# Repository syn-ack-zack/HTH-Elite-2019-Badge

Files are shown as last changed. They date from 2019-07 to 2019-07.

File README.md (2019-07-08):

# Hackers Teaching Hackers 2019 Badge
This repository contains the hardware and software source code to fabrciate the HTH 2019 Badge. Details on the use and flashing of the badge can be found below. 

HTH Badge

## Badge Hardware Specs
* ESP32
* Atmel 32u4
* 96×64 Graphic Full Color OLED Display
* 19x Mini NeoPixel RGB LEDs
* 4 tactile buttons
* 8 Mb Storage
* 1 2x3 "Shitty Add On" Connector
* Powered via 2 AA batteries or USB

## Badge Functions
* LoRa Arsenal
	* LoRa 915Mhz Tactile Button Chat
	* LoRa 915Mhz Web App Chatroom
* WiFi Tools
	* 802.11 channel activity monitor
	* Access point scanner / Open AP detector
	* Packet Monitor and Deauth sniffer
	* Can act as a client or access point (modify config.json via SPIFFS to update AP connection details)
	* Webserver (edit filesystem files, trigger payloads remotely)
	* NTP client
* HID Toolkit (Not Working)
	* An issue with the serial communication currently prevents the ESP32 from controlling the Atmega. 
	* Any HID functionality must be standalone and flashed to the Atmega.
	* This repo will be updated as any changes occur.
	
* LED patterns and OLED graphics
* Misc. extras

## Usage Instructions
### Power Switch
In order to turn on the device, it must be powered via 2 AA batteries or USB. The main power switch is located in the center.

### Buttons / UI

Up and Down is on the left side of the OLED, and Left and Right is on the right side of the OLED.

In order to go into a menu or run a program, click the right button. To exit most applications, click the left button. Some programs like the snake game require all 4 buttons so there is no way to clean exit, a power cycle is needed. 

### HTH NET (LoRa 915Mhz)
This badge contains an SX1278 LoRa transceiver which allows for long range low bandwidth communication using the LoRa protocol over 915Mhz. Each badge is capable of receiving and sending messages using this frequency by utilizing the HTH NET feature of the badge. 

Once you start the chat it will display any received message on the screen. Follow the on screen prompts to type out and send messages. The '~' is used as a delimiter to signify the end of a typed message. 

Alternatively you can utililze the Webserver by first starting up the Access Point at `WiFi Server Tools -> AP Start`. Connect to this network and then start up the Webserver at `WiFi Server Tools -> Webserver Start`. Navigate to the indicated IP, http://10.0.1.5/ to access the web app. HTH Net can be utilized here to have a more convenient interface to send and recieve LoRa messages. 



### Webserver
Navigate to WiFi Server Tools -> Webserver Start. You can access the webserver if running an AP or if connected. The pages are protected through basic authentication, username and password generated dynamically and is provided on the screen.

A SPIFFS Editor can be used to edit the flash filesystem on the badge. This is useful to modify config files which are used in several instances. For instance, to have your badge connect to another wireless network, you configure the ESSID and Password in `config.json`. 

### Bling
There are 40+ LED patterns included. You can also trigger each type of pattern individually. 

## Configuration / Customization
### Settings menu in OLED UI
There are individual settings for OLED and LED brightness. Region setting is related to WiFi channel scanning.

### JSON configuration files
There are 4 different json files in SPIFFS. There are a couple ways to edit these files and get them loaded on the badge, but the easiest is through the webserver.
1. config.json = Main device configuration. Includes parameters such as LED and OLED brightness settings, ssid/password if connecting to a wireless client network, region information, and google auth HMAC. 
2. lin.json / win.json = Configuration files for the Linux and Windows KB/M payloads. 
3. static.json = Configuration file for the stored static strings. 

## Compiling Instructions
These instructions will get you a copy of the project up and running on your local machine.
### Prerequisites
What things you need to install the software and how to install them
```
1. Arduino / compiler
2. SparkFun Pro Micro v3 com driver
https://learn.sparkfun.com/tutorials/pro-micro--fio-v3-hookup-guide/installing-windows
https://learn.sparkfun.com/tutorials/pro-micro--fio-v3-hookup-guide/installing-mac--linux
3. Libraries
  https://raw.githubusercontent.com/sparkfun/Arduino_Boards/master/IDE_Board_Manager/package_sparkfun_index.json
  https://github.com/adafruit/Adafruit_NeoPixel
  https://github.com/adafruit/Adafruit-GFX-Library
  https://github.com/adafruit/Adafruit_CircuitPlayground
  https://github.com/kitesurfer1404/WS2812FX
  https://github.com/me-no-dev/ESPAsyncWebServer
  https://github.com/me-no-dev/AsyncTCP
  https://github.com/bblanchon/ArduinoJson
  https://github.com/me-no-dev/arduino-esp32fs-plugin
  https://github.com/sandeepmistry/arduino-LoRa
  Manually copy the SSD_13XX and qMenuSystem folders to Arduino libraries folder. We included a snapshot of the other libraries used in case newer versions break our code.
4. 3.3v FTDI serial cable
5. Hackers Teaching Hackers 2019 Badge
```
### Compiling / Flashing Atmel Code
* Set the board to SparkFun Pro Micro
* Set the processor as ATmega32u4 3.3v and NOT the 5v one

### Compiling / Flashing ESP Code
* Set the board to SparkFun ESP32 Thing

#### Programming through FTDI port 
To interface with the ESP32 over FTDI serial, you will need a FTDI USB adapter. These can be found online or at some retailers like MicroCenter. [FTDI Adapter on Amazon](https://www.amazon.com/HiLetgo-FT232RL-Converter-Adapter-Breakout/dp/B00IJXZQ7C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)

1. Flash the atmel with the 'atmel-esp32ftdi-pin7' code first via the USB connection. this will toggle pin 7 and the rx/tx switch to change the serial port communiction to the FTDI port. 
2. Connect FTDI cable to the board while holding the left button down (which is on the right side, top button)
3. Upload code.
4. You can optionally flash the 'atmel-km-relay' code back to the atmel. Most serial functionality isn't working correctly at this time, however the mouse jiggler feature is configured to work when plugged in. Note that you may need to reset the the atmel by shorting GND to [Pin 13](https://www.arduino.cc/en/Hacking/PinMapping32u4) before succesfully reflashing. 

#### Programming through USB port / Atmel
Pass through programming doesn't work at the time of writing. Communication is passed through, but something is holding up the ESP32 from fully going into the programming mode

### Uploading SPIFFS files
The keyboard/mouse payloads, configuration files, webserver files are all files that are loaded into a special section in storage marked as SPIFFS. While still having pin 7 set to allow for the FTDI connection, use the 'ESP32 Sketch Data Upload' function in the tools menu. This will compress and compile all the files in the 'data' folder, and upload it. 

## Authors / Contributors
* **@syn-ack-zack**

## Acknowledgments
* Thanks to all contributes and maintainers of any codebase which was used or referenced. 
* Special thanks to Hacker Warehouse and Garret Gee for the work on their [DC26 badge](https://github.com/hackerwarehouse/HW-DC26-Badge). Much of the materials around the core components (esp32 / atmega34u ) was referenced from Hacker Warehouse's open sourced badge.

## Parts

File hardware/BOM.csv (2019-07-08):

 | Note | part number | Quantity | Description | Alternative Part Number | Reference Designator
 |  | CL10C220JB8NNNC | 2 | 22PF 50V NP0 0603 Capacitor | C1608C0G1H220G080AA | C2, C3
 | 5-7work days | F931C106MAAAJ6 | 2 | 10uf Tantalum Capacitor 1206 16V 20% | F931C106MAA | C4, C8
 |  | C1608X6S1C475K080AC | 1 | 4.7UF 16V X5R 0603 |  | C46
 |  | CL10A106MA8NRNC | 4 | 10uF 25V 20% 0603 Capacitor |  | C6, C9, C10, C24
 | TME MOQ:100pcs 5-7work days | CL10B103KC8NNNC | 1 | .01uf/10nf 100V 0603 10% Capacitor |  | C20
 |  | CC0603MRY5V6BB105 | 5 | 1uf 16V 10% 0603 Capacitor | CL10A105KO8NNNC | C1, C29, C44, C45, C47
 | 5-7work days | 06033C104KAZ2A | 27 | 0.1uf 25V 10% 0603 Capacitor | CL10B104KA8NNNC | C5, C7, C21, C23, C25, C26, C27, C28, C30, C31, C32, C33, C34, C35, C36, C37, C38, C39, C40, C41, C42, C43, C48, C49, C50, C51, C55
 |  | VJ0603Y332KXJCW1BC | 1 | 3.3nf 16V 10% 0603 Capacitor |  | C19
 | 5-7work days | GRM1885C2A101JA01D | 1 | 100pf/0.1nf 100V 0603 Capacitor |  | C22
 |  | C1608C0G1H100C080AA | 2 | 10pF 脗卤0.25pF 50V Ceramic Capacitor C0G, NP0 0603 |  | C13, C16
 |  | CL10C5R6DB8NNNC | 1 | 5.6pF Ceramic Capacitor +-0.5pF 50V 0603 |  | C11
 |  | CC0603JRNPO9BN150 | 2 | CAP CER 15PF 50V C0G/NPO 0603 |  | C14, C15
 |  | CL10C2R4CB8NNNC | 1 | CAP CER 2.4PF 50V C0G/NP0 0603 |  | C12
 |  | CL10B271KB8NNNC | 2 | CAP CER 270PF 50V X7R 0603 |  | C17, C18
 |  | SS1P3L-M3/84A | 1 | SS1P3L Schottky Diode 30V 1A |  | D3
 |  | B140HW-7 | 2 | DIODE SCHOTTKY 40V 1A SOD123 |  | D2, D5
 | 5-7work days | 1N914BWS | 1 | Diode Standard 75V 150mA SOD-323F |  | D1
 | MOQ：1500pcs 1500pcs / bag | SK6812MINI | 19 | 3535 RGB Addressable LED |  | LED1, LED2, LED3, LED4, LED5, LED6, LED7, LED8, LED9, LED10, LED11, LED12, LED13, LED14, LED15, LED16, LED17, LED18, LED19
 | 7-10work days | AYZ0202AGRLC | 1 | DPDT Slide Switch (On/Off) SMT |  | S1
 | 7-10work days | TL3301NF100QG | 4 | Black Momentary Push Button - SMD |  | U$1, U$2, U$3, U$4
 |  | 10118194-0001LF | 1 | USB Micro-B RECPT SMD Connector |  | U$6
 | 5-7work days | BC2AAPC | 1 | Battery Holder 2-AA TH |  | U$5
 |  | ATMEGA32U4-MU | 1 | ATMEGA32U4-MU Microcontroller QFN |  | U4
 | 5-7work days | FAN5331SX | 1 | LED Driver Regulator 1A SOT23-5 |  | U1
 | 5-7work days | MIC5209-3.3YS-TR | 1 | IC REG LINEAR 3.3V 500MA SOT223 |  | U$7
 |  | 74LVC1G3157GW,125 | 2 | IC MUX/DEMUX 2X1 6TSSOP |  | U$8, U$9
 | ESP32-D0WDQ6 QFN 6*6 | ESP3212 | 1 | ESP3212 |  | U2
 | 5-7work days | TPS2113ADRBR | 1 | IC OR CTRLR SRC SELECT 8SON |  | U$10
 | 5-7work days | W25Q64JVSSIM TR | 1 | IC FLASH 64MBIT SPI 8SOIC W25Q64JVSSIM TR |  | U5
 | 5-7work days | SRU5018-100Y | 1 | 10 uH Inductor 1.8A 5028 |  | L1
 |  | HK16082N7S-T | 1 | FIXED IND 2.7NH 300MA 100 MOHM |  | L2
 |  | UG-9664HDDAG01 | 1 | 0.95 inch (96 x 64) Pixel Full Color Passive OLED LCD |  | LCD1
 |  | RC0603JR-07100KL | 3 | 100K Resistor 0603 1/10W 5% |  | R2, R6, R12
 |  | ERJ-3GEYJ102V | 1 | 1K OHM 5% 1/10W 0603 Resistor | RC0603JR-071KL | R13
 |  | RC0603JR-0710KL | 6 | 10K Resisitor 0603 1/10W 5% |  | R1, R3, R5, R7, R8, R10
 |  | RC0603FR-071ML | 1 | 1M Resistor 0603 1/10W 1% |  | R4
 |  | RC0603JR-0722RL | 2 | 22 ohm Resistor 0603 1/10W 5% |  | R14, R15
 |  | RC0603FR-0720KL | 2 | RES SMD 20K OHM 1% 1/10W 0603 |  | R9, R11
 | 5-7work days | ABM3B-8.000MHZ-B2-T | 1 | 8.0 MHz Crystal 5 mm x 3.2 mm |  | Y1
 | 5-7work days | ABS07-32.768KHZ-T | 1 | 32.768 KHz Crystal FC-135 32.7680KA-A3 | FC-135 32.7680KA-A3 | X2
 | 5-7work days | TSX-3225 26.0000MF09Z-AC0 | 1 | Crystal 26MHz 3.2 x 2.5 |  | Y2
0.5KG

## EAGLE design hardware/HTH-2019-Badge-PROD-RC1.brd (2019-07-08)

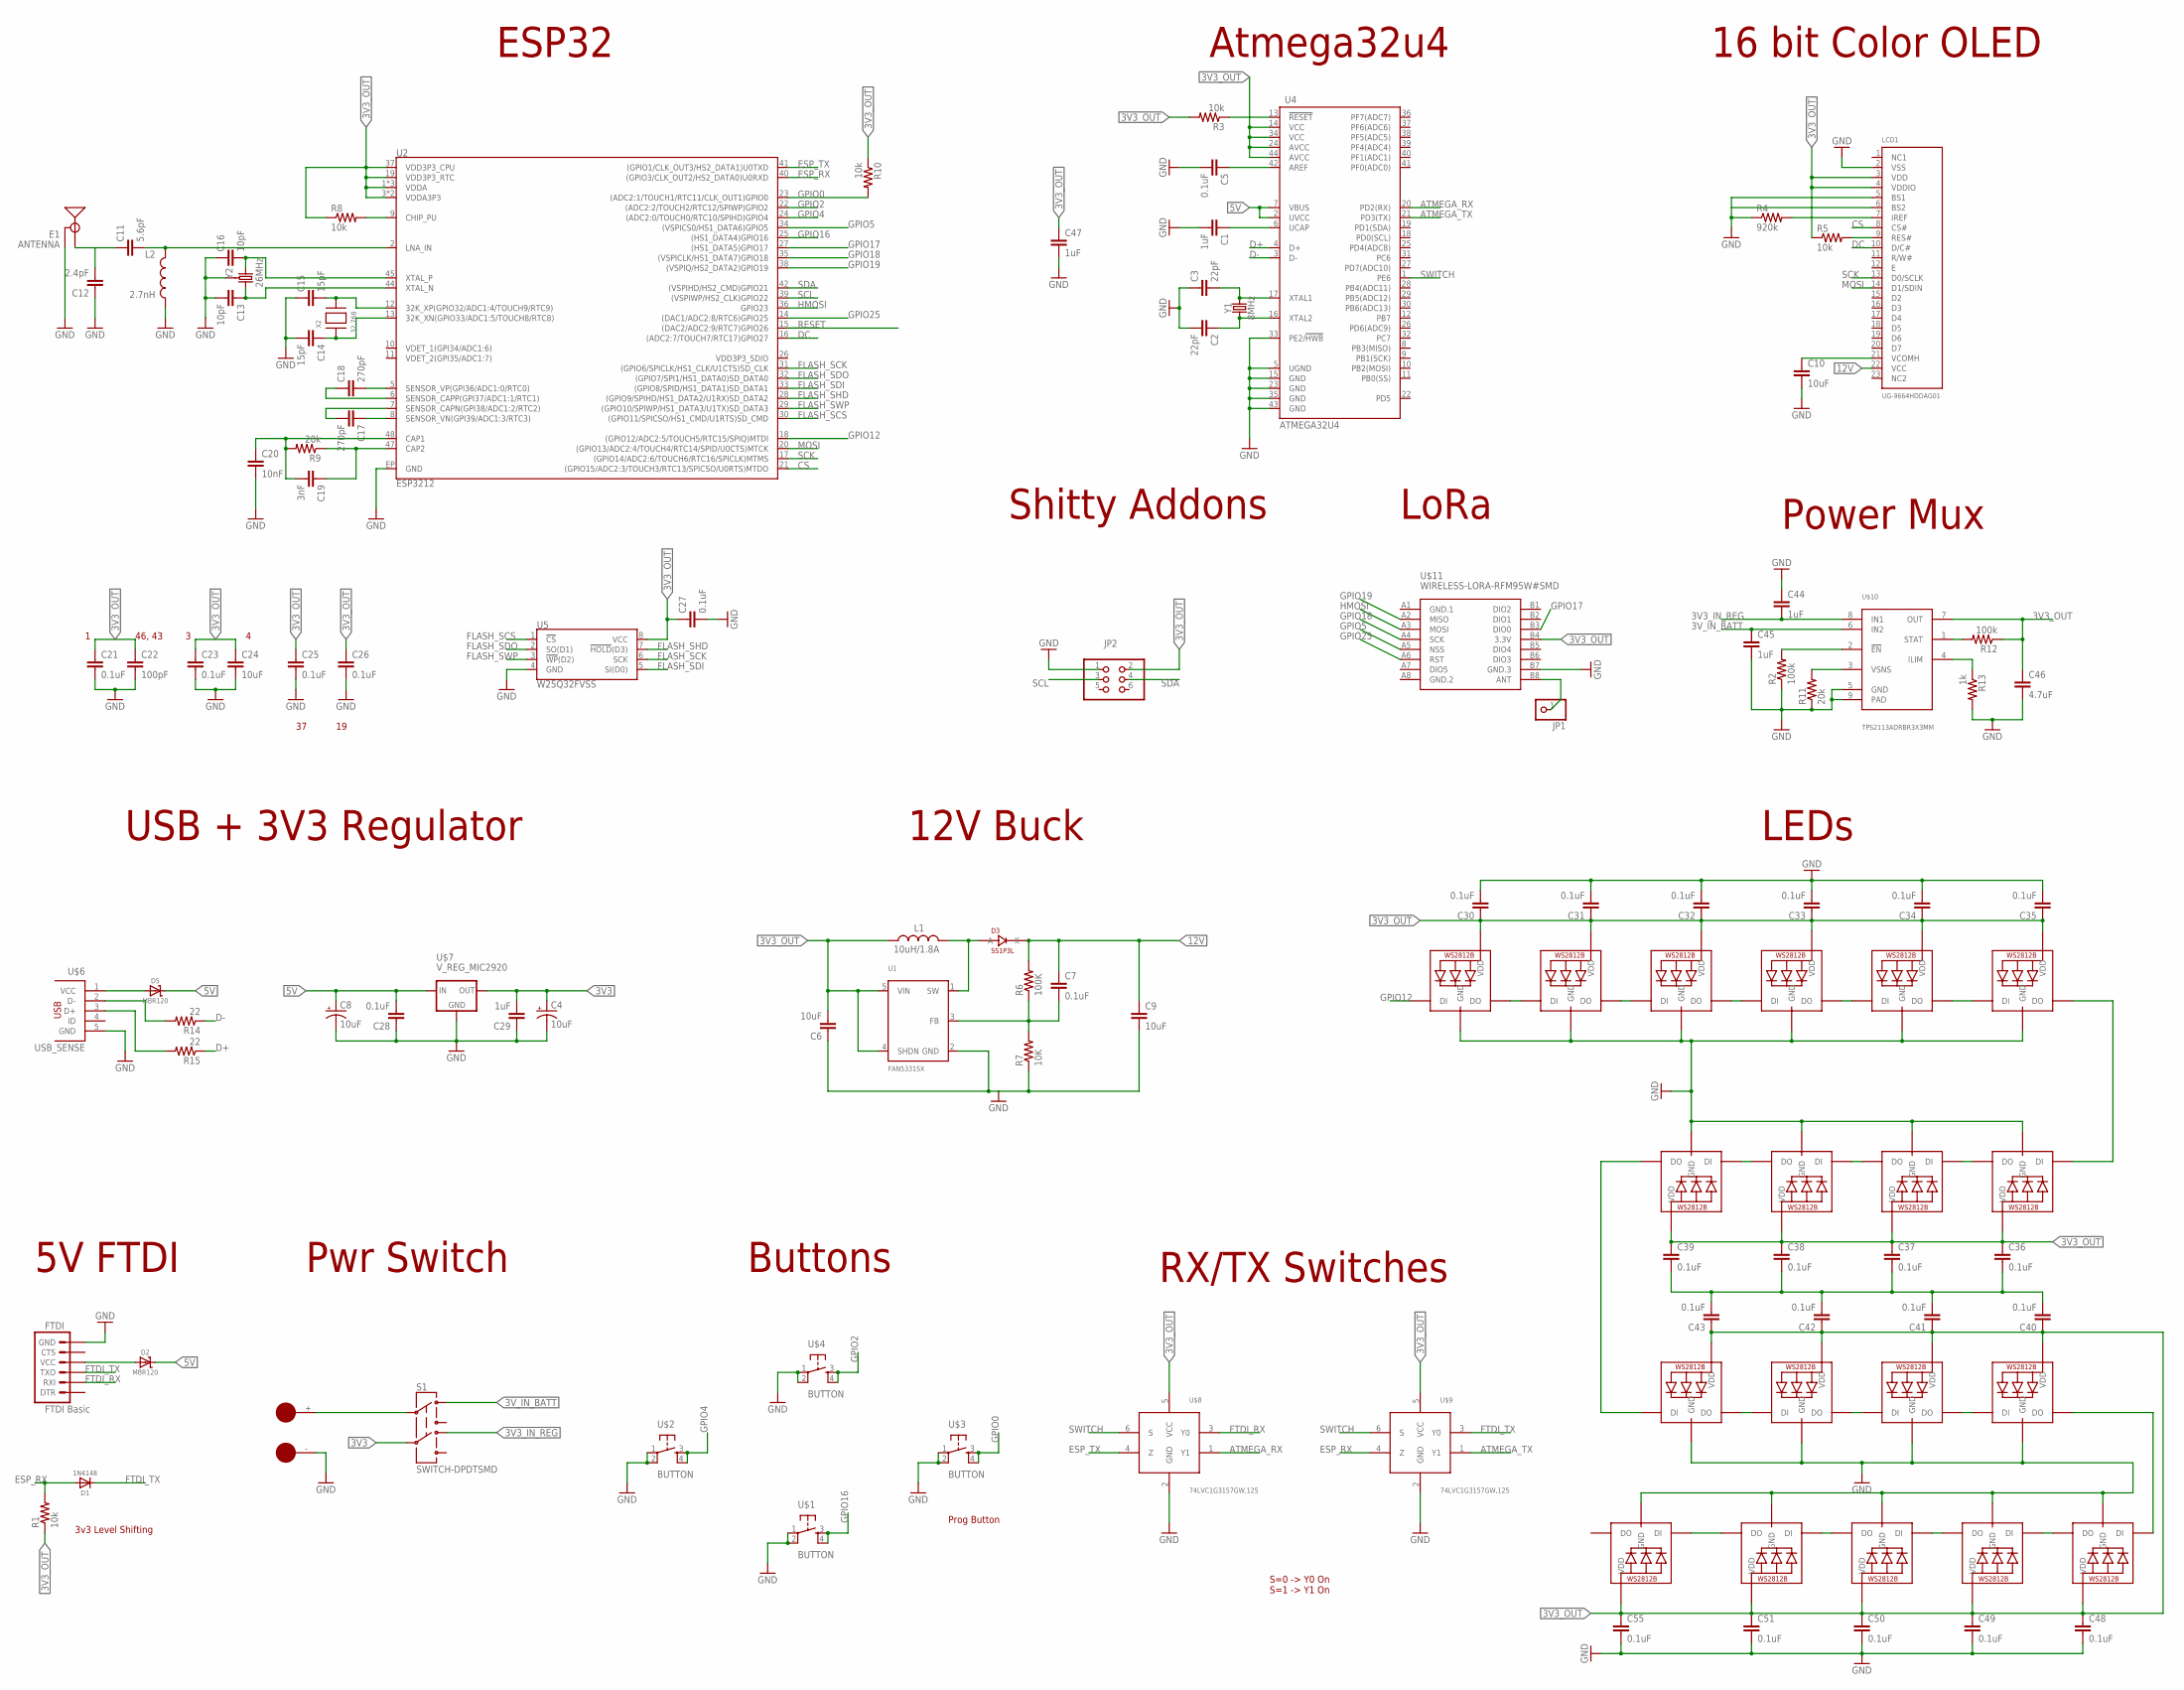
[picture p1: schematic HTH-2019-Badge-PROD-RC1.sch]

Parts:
C1, C29, C44, C45, C47: 1uF; CAP0603
C2, C3: 22pF; CAP0603
C4, C8: 10uF; EIA3216
C5, C7, C21, C23, C25, C26, C27, C28, C30, C31, C32, C33, C34, C35, C36, C37, C38, C39, C40, C41, C42, C43, C48, C49, C50, C51, C55: 0.1uF; CAP0603
C6, C9, C10, C24: 10uF; CAP0603
C11: 5.6pF; CAP0603
C12: 2.4pF; CAP0603
C13, C16: 10pF; CAP0603
C14, C15: 15pF; CAP0603
C17, C18: 270pF; CAP0603
C19: 3nF; CAP0603
C20: 10nF; CAP0603
C22: 100pF; CAP0603
C46: 4.7uF; CAP0603
D1: 1N4148; SOD-323
D2, D5: MBR120; SOD-123
D3: SS1P3L; DO220AAL
E1: ANTENNA; TRACE_ANTENNA_2.4GHZ_25.7MM_TUNED
FTDI: FTDI Basic; 1X06
JP1: PINHD-1X1; 1X01
JP2: PINHD-2X3; 2X03
L1: 10uH/1.8A; SRU5028
L2: 2.7nH; 0603
LCD1: UG-9664HDDAG01; UG-9664HDDAG01_WRAPAROUND
LED1, LED2, LED3, LED4, LED5, LED6, LED7, LED8, LED9, LED10, LED11, LED12, LED13, LED14, LED15, LED16, LED17, LED18, LED19: WS2812B3535; LED3535
R1, R3, R5, R8, R10: 10k; RES-0603
R2, R12: 100k; RES-0603
R4: 920k; RES-0603
R6: 100K; RES-0603
R7: 10K; RES-0603
R9, R11: 20k; RES-0603
R13: 1k; RES-0603
R14, R15: 22; RES-0603
S1: SWITCH-DPDTSMD; AYZ0202
U1: FAN5331SX; SOT23-5
U2: ESP3212; QFN48-0.4MM
U4: ATMEGA32U4; QFN-44-NOPAD_1:1-OUTFAKES
U5: W25Q32FVSS; SOIC-8
U$1, U$2, U$3, U$4: BUTTON
U$5: BAT_HOLD; AA
U$6: USB_SENSE; USB-MICRO-TH-SUPPORT
U$7: V_REG_MIC2920; SOT223
U$8, U$9: 74LVC1G3157GW,125; SOT-363
U$10: TPS2113ADRBR3X3MM; 8-VDFN
U$11: WIRELESS-LORA-RFM95W#SMD
X2: 32.768; XTAL3215
Y1: 8MHz; CRYSTAL-SMD-5X3.2-4PAD
Y2: 26MHz; CRYSTAL-SMD-3.2X2.5

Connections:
3V3: C4.A (+), C29.2, S1.5, U$7.3 (OUT)
3V3_IN_REG: C44.2, S1.4, U$10.8 (IN1)
3V3_OUT: C6.2, C21.1, C22.1, C23.1, C24.1, C25.1, C26.1, C27.1, C30.1, C31.1, C32.1, C33.1, C34.1, C35.1, C36.1, C37.1, C38.1, C39.1, C40.1, C41.1, C42.1, C43.1, C46.1, C47.1, C48.1, C49.1, C50.1, C51.1, C55.1, JP2.2, L1.1, LCD1.3 (VDD), LCD1.4 (VDDIO), LED1.2 (VDD), LED2.2 (VDD), LED3.2 (VDD), LED4.2 (VDD), LED5.2 (VDD), LED6.2 (VDD), LED7.2 (VDD), LED8.2 (VDD), LED9.2 (VDD), LED10.2 (VDD), LED11.2 (VDD), LED12.2 (VDD), LED13.2 (VDD), LED14.2 (VDD), LED15.2 (VDD), LED16.2 (VDD), LED17.2 (VDD), LED18.2 (VDD), LED19.2 (VDD), R1.1, R3.2, R5.1, R8.1, R10.1, R12.1, U1.4 (SHDN), U1.5 (VIN), U2.1 (VDDA), U2.3 (VDDA3P3), U2.4 (VDDA3P3), U2.19 (VDD3P3_RTC), U2.37 (VDD3P3_CPU), U2.43 (VDDA), U2.46 (VDDA), U4.14 (VCC), U4.24 (AVCC), U4.34 (VCC), U4.44 (AVCC), U5.8 (VCC), U$8.5 (VCC), U$9.5 (VCC), U$10.7 (OUT), U$11.B4 (3.3V)
3V_IN_BATT: C45.1, S1.1, U$10.6 (IN2)
5V: C8.A (+), C28.2, D2.C, D5.C, U4.2 (UVCC), U4.7 (VBUS), U$7.1 (IN)
12V: C7.1, C9.1, D3.P$1 (K), LCD1.22 (VCC), R6.2
ATMEGA_RX: U4.20 (PD2(RX)), U$8.1 (Y1)
ATMEGA_TX: U4.21 (PD3(TX)), U$9.1 (Y1)
CS: LCD1.8 (CS#), U2.21 ((GPIO15/ADC2:3/TOUCH3/RTC13/SPICSO/U0RT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)
D+: R15.1, U4.4 (D+)
D-: R14.1, U4.3 (D-)
DC: LCD1.10 (D/C#), U2.16 ((ADC2:7/TOUCH7/RTC17)GPIO27)
ESP_RX: D1.A, R1.2, U2.40 ((GPIO3/CLK_OUT2/HS2_DATA0)U0RXD), U$9.4 (Z)
ESP_TX: U2.41 ((GPIO1/CLK_OUT3/HS2_DATA1)U0TXD), U$8.4 (Z)
FLASH_SCK: U2.31 ((GPIO6/SPICLK/HS1_CLK/U1CTS)SD_CLK), U5.6 (SCK)
FLASH_SCS: U2.30 ((GPIO11/SPICSO/HS1_CMD/U1RTS)SD_CMD), U5.1 (!CS!)
FLASH_SDI: U2.33 ((GPIO8/SPID/HS1_DATA1)SD_DATA1), U5.5 (SI(D0))
FLASH_SDO: U2.32 ((GPIO7/SPI1/HS1_DATA0)SD_DATA0), U5.2 (SO(D1))
FLASH_SHD: U2.28 ((GPIO9/SPIHD/HS1_DATA2/U1RX)SD_DATA2), U5.7 (!HOLD!(D3))
FLASH_SWP: U2.29 ((GPIO10/SPIWP/HS1_DATA3/U1TX)SD_DATA3), U5.3 (!WP!(D2))
FTDI_RX: FTDI.2 (RXI), U$8.3 (Y0)
FTDI_TX: D1.C, FTDI.3 (TXO), U$9.3 (Y0)
GND: C1.2, C2.2, C3.1, C4.C (-), C5.2, C6.1, C8.C (-), C9.2, C10.2, C12.1, C13.2, C14.2, C15.1, C16.1, C20.2, C21.2, C22.2, C23.2, C24.2, C25.2, C26.2, C27.2, C28.1, C29.1, C30.2, C31.2, C32.2, C33.2, C34.2, C35.2, C44.1, C45.2, C46.2, C47.2, C48.2, C49.2, C50.2, C51.2, C55.2, E1.GND, E1.GND2 (GND), FTDI.6 (GND), JP2.1, L2.2, LCD1.2 (VSS), LCD1.5 (BS1), LED1.4 (GND), LED2.4 (GND), LED3.4 (GND), LED4.4 (GND), LED5.4 (GND), LED6.4 (GND), LED7.4 (GND), LED8.4 (GND), LED9.4 (GND), LED10.4 (GND), LED11.4 (GND), LED12.4 (GND), LED13.4 (GND), LED14.4 (GND), LED15.4 (GND), LED16.4 (GND), LED17.4 (GND), LED18.4 (GND), LED19.4 (GND), R2.1, R4.1, R7.1, R11.1, R13.2, U1.2 (GND), U2.EP (GND), U4.5 (UGND), U4.15 (GND), U4.23 (GND), U4.33 (PE2/!HWB), U4.35 (GND), U4.43 (GND), U5.4 (GND), U$1.1, U$1.2, U$2.1, U$2.2, U$3.1, U$3.2, U$4.1, U$4.2, U$5.-, U$6.5 (GND), U$7.2 (GND), U$7.4 (GND), U$8.2 (GND), U$9.2 (GND), U$10.5 (GND), U$10.9 (PAD), U$11.B7 (GND.3), Y2.2 (GND), Y2.4 (GND)
GND.1: U$11.A1 (GND.1)
GND.2: U$11.A8 (GND.2)
GPIO0: R10.2, U2.23 ((ADC2:1/TOUCH1/RTC11/CLK_OUT1)GPIO0), U$3.3, U$3.4
GPIO2: U2.22 ((ADC2:2/TOUCH2/RTC12/SPIWP)GPIO2), U$4.3, U$4.4
GPIO4: U2.24 ((ADC2:0/TOUCH0/RTC10/SPIHD)GPIO4), U$2.3, U$2.4
GPIO5: U2.34 ((VSPICS0/HS1_DATA6)GPIO5), U$11.A5 (NSS)
GPIO12: LED5.1 (DI), U2.18 ((GPIO12/ADC2:5/TOUCH5/RTC15/SPIQ)MTDI)
GPIO16: U2.25 ((HS1_DATA4)GPIO16), U$1.3, U$1.4
GPIO17: U2.27 ((HS1_DATA5)GPIO17), U$11.B3 (DIO0)
GPIO18: U2.35 ((VSPICLK/HS1_DATA7)GPIO18), U$11.A4 (SCK)
GPIO19: U2.38 ((VSPIQ/HS2_DATA2)GPIO19), U$11.A2 (MISO)
GPIO25: U2.14 ((DAC1/ADC2:8/RTC6)GPIO25), U$11.A6 (RST)
HMOSI: U2.36 (GPIO23), U$11.A3 (MOSI)
MOSI: LCD1.14 (D1/SDIN), U2.20 ((GPIO13/ADC2:4/TOUCH4/RTC14/SPID/U0CTS)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)
unnamed: C3.2, U4.17 (XTAL1), Y1.3 (2)
unnamed: R3.1, U4.13 (!RESET)
unnamed: C1.1, U4.6 (UCAP)
unnamed: C5.1, U4.42 (AREF)
unnamed: R14.2, U$6.2 (D-)
unnamed: C10.1, LCD1.21 (VCOMH)
unnamed: D3.P$2 (A), L1.2, U1.1 (SW)
unnamed: C2.1, U4.16 (XTAL2), Y1.1
unnamed: LED1.1 (DI), LED14.3 (DO)
unnamed: C7.2, R6.1, R7.2, U1.3 (FB)
unnamed: LCD1.7 (IREF), R4.2
unnamed: S1.2, U$5.+
unnamed: R8.2, U2.9 (CHIP_PU)
unnamed: C16.2, U2.45 (XTAL_P), Y2.1
unnamed: C11.1, C12.2, E1.ANT (SIGNAL)
unnamed: LED1.3 (DO), LED2.1 (DI)
unnamed: D2.A, FTDI.4 (VCC)
unnamed: LED5.3 (DO), LED6.1 (DI)
unnamed: C19.2, C20.1, R9.2, U2.48 (CAP1)
unnamed: C11.2, L2.1, U2.2 (LNA_IN)
unnamed: C13.1, U2.44 (XTAL_N), Y2.3 (2)
unnamed: C19.1, R9.1, U2.47 (CAP2)
unnamed: C15.2, U2.12 (32K_XP(GPIO32/ADC1:4/TOUCH9/RTC9)), X2.P$2
unnamed: C14.1, U2.13 (32K_XN(GPIO33/ADC1:5/TOUCH8/RTC8)), X2.P$1
unnamed: C18.2, U2.5 (SENSOR_VP(GPI36/ADC1:0/RTC0))
unnamed: C18.1, U2.6 (SENSOR_CAPP(GPI37/ADC1:1/RTC1))
unnamed: C17.2, U2.7 (SENSOR_CAPN(GPI38/ADC1:2/RTC2))
unnamed: C17.1, U2.8 (SENSOR_VN(GPI39/ADC1:3/RTC3))
unnamed: D5.A, U$6.1 (VCC)
unnamed: LED6.3 (DO), LED7.1 (DI)
unnamed: LED7.3 (DO), LED8.1 (DI)
unnamed: LED8.3 (DO), LED9.1 (DI)
unnamed: LED9.3 (DO), LED11.1 (DI)
unnamed: LED11.3 (DO), LED13.1 (DI)
unnamed: LED10.1 (DI), LED13.3 (DO)
unnamed: LED10.3 (DO), LED12.1 (DI)
unnamed: LED12.3 (DO), LED14.1 (DI)
unnamed: LED2.3 (DO), LED3.1 (DI)
unnamed: LED3.3 (DO), LED4.1 (DI)
unnamed: LED15.3 (DO), LED16.1 (DI)
unnamed: LED16.3 (DO), LED17.1 (DI)
unnamed: R15.2, U$6.3 (D+)
unnamed: LED17.3 (DO), LED18.1 (DI)
unnamed: JP1.1, U$11.B8 (ANT)
unnamed: C36.2, C37.2, C38.2, C39.2, C40.2, C41.2, C42.2, C43.2
unnamed: LED4.3 (DO), LED15.1 (DI)
unnamed: LED18.3 (DO), LED19.1 (DI)
unnamed: R2.2, U$10.2 (!EN)
unnamed: R11.2, U$10.3 (VSNS)
unnamed: R12.2, U$10.1 (STAT)
unnamed: R13.1, U$10.4 (ILIM)
RESET: LCD1.9 (RES#), R5.2, U2.15 ((DAC2/ADC2:9/RTC7)GPIO26)
SCK: LCD1.13 (D0/SCLK), U2.17 ((GPIO14/ADC2:6/TOUCH6/RTC16/SPICLK)MTMS)
SCL: JP2.3, U2.39 ((VSPIWP/HS2_CLK)GPIO22)
SDA: JP2.4, U2.42 ((VSPIHD/HS2_CMD)GPIO21)
SWITCH: U4.1 (PE6), U$8.6 (S), U$9.6 (S)

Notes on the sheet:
ESP32
Atmega32u4
16 bit Color OLED
USB + 3V3 Regulator
5V FTDI
12V Buck
Pwr Switch
Buttons
Shitty Addons
LEDs
S=0 -> Y0 On S=1 -> Y1 On
RX/TX Switches
46, 43
Power Mux
3v3 Level Shifting
Prog Button
LoRa

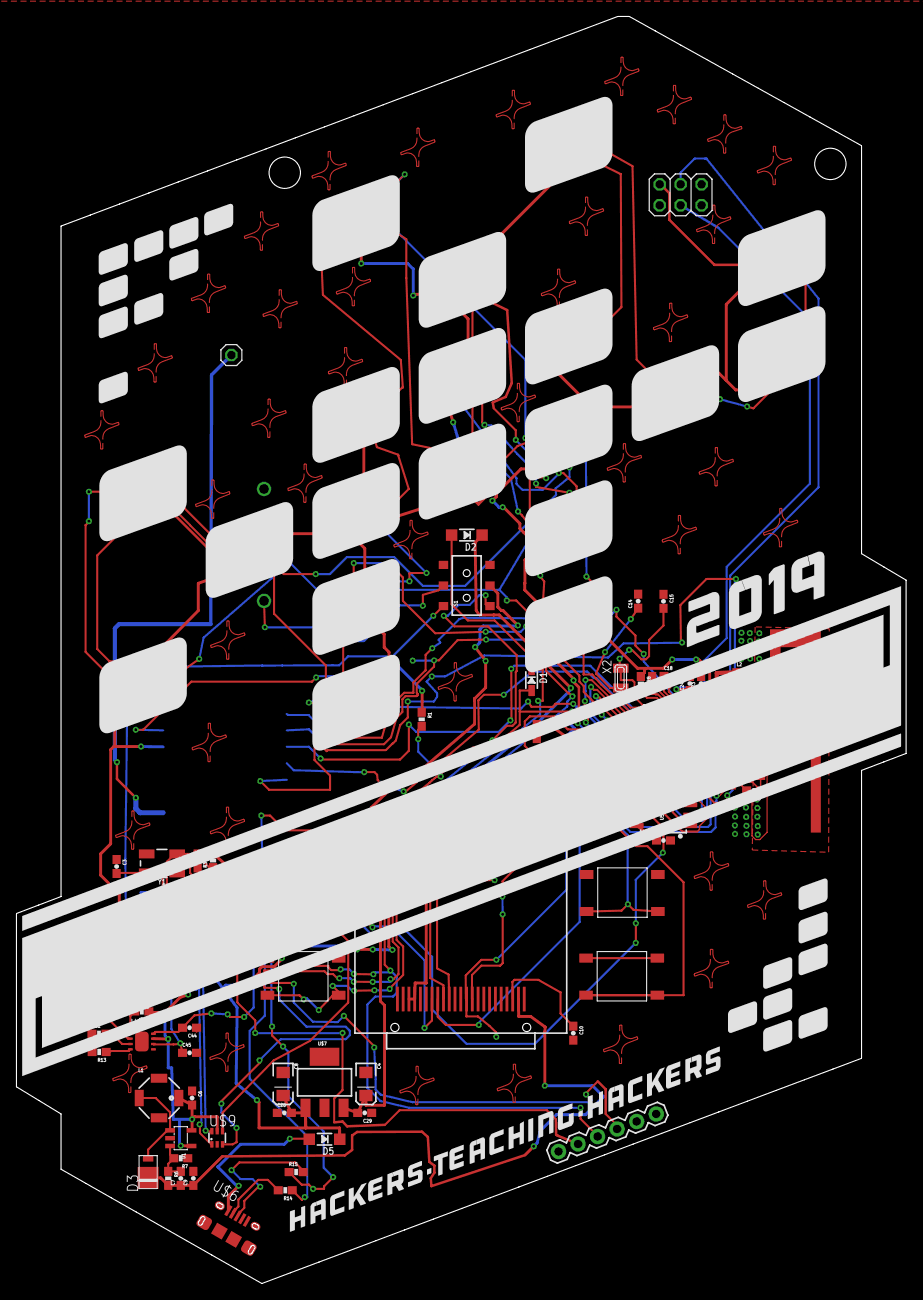
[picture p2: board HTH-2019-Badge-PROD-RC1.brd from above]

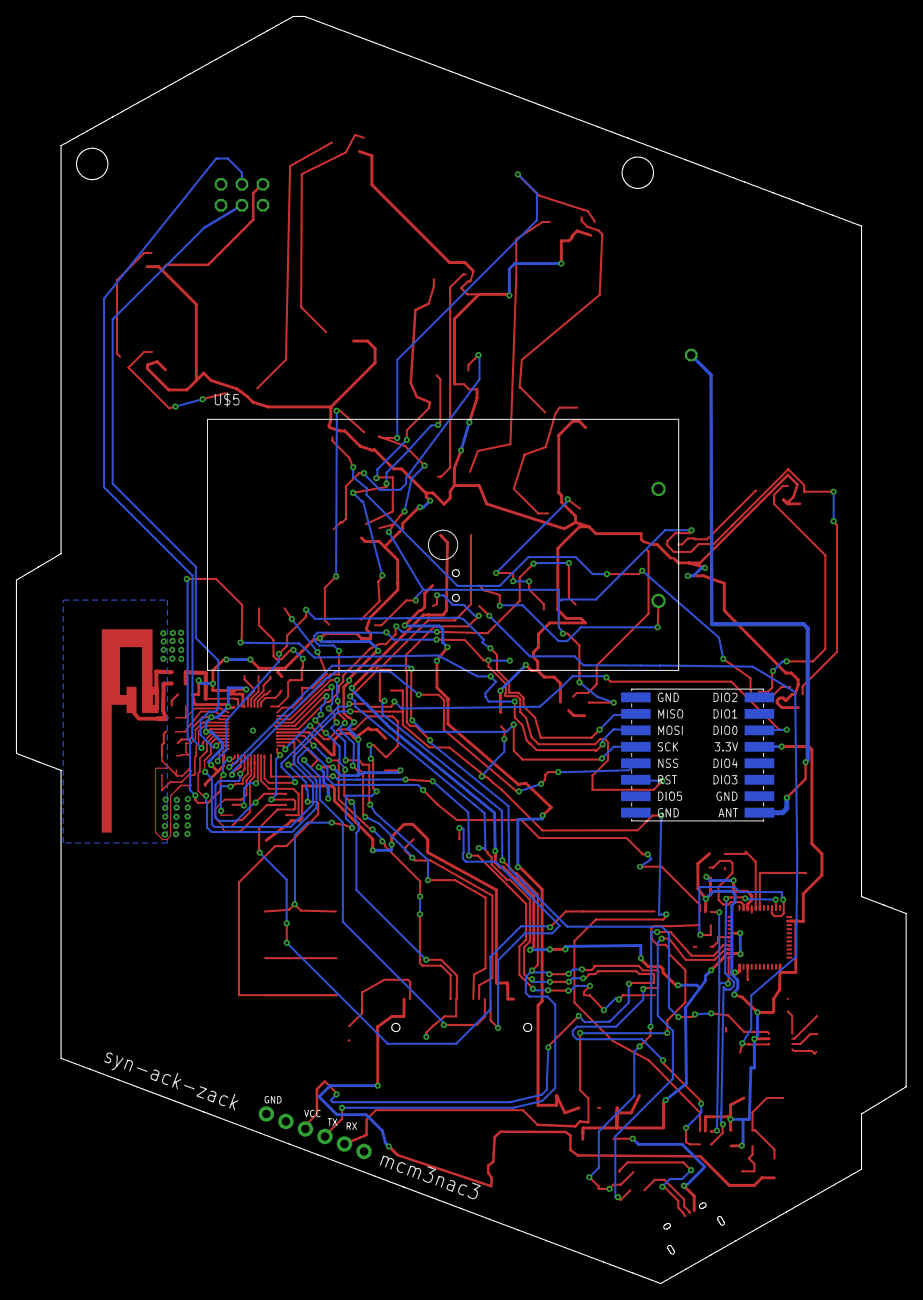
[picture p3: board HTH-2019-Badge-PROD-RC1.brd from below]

Board: 2 copper layers, 108.0 x 153.8 mm, 116 parts (2 on the bottom side), 91 nets.

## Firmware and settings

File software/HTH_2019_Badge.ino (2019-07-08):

#ifdef __AVR__
  #include <avr/power.h>
#endif
#include "FS.h"
#include "SPIFFS.h"
#include <LoRa.h>    // this is the one by Sandeep Mistry, 
#include <SPI.h>
#include <WiFi.h>
#include <Adafruit_NeoPixel.h>
#include <qMenuDisplay.h>
#include <qMenuSystem.h>
#include <SSD_13XX.h>
#include <WS2812FX.h>
#include <HTTPClient.h>


#include "about.h"
#include "blinky.h"
#include "core.h"
#include "debug.h"
#include "extras.h"
#include "graphics.h"
#include "hidarsenal.h" 
#include "mainmenu.h"
#include "settings.h"
#include "wifi-client.h"
#include "wifi-pkt1.h"
#include "wifi-scanner.h"
#include "wifi-server.h"
#include "soc/soc.h"
#include "soc/rtc_cntl_reg.h"
#include "lorareceiver.h"

Adafruit_NeoPixel pixels = Adafruit_NeoPixel(NUMPIXELS, PIN, NEO_GRB + NEO_KHZ800);
WS2812FX ws2812fx = WS2812FX(NUMPIXELS, PIN, NEO_GRB + NEO_KHZ800);
SSD_13XX mydisp( /*cs*/ 15, /*dc*/ 27, /*rst*/ 26);
qMenuSystem menu=qMenuSystem(&mydisp);

const byte left = 0; 
const byte down = 16; 
const byte right = 2; 
const byte up = 4;  

volatile byte btncounter = 0;
volatile byte btnid  = 0;
byte appmode = 0;

bool msgReceived = false;
String storedMsg = "";

volatile byte region_id = 1;
volatile byte oledbright;
volatile byte ledsbright;
String ISSID;
String IPSWD;
int NTP_OFFSET;
String GOOGLEAUTH;
byte region_unlocked = 0;

long debouncing_time = 250;
unsigned long last_micros = 0;

void UP(){
  if((long)(micros() - last_micros) >= debouncing_time * 1000) {
    if (appmode){      
    }
    else {
      btncounter ++;
    }
    btnid = 3;
    last_micros = micros();
  }
}

void DOWN(){
  if((long)(micros() - last_micros) >= debouncing_time * 1000) 
  {
    if (appmode){
    }
    else {
      btncounter ++;
    }
    btnid = 2;
    last_micros = micros();
  }
}

void RIGHT(){
  if((long)(micros() - last_micros) >= debouncing_time * 1000) {
    if (appmode){
    }
    else {
      btncounter ++;
    }
    btnid = 1;
    last_micros = micros();
  }
}

void LEFT(){
  if((long)(micros() - last_micros) >= debouncing_time * 1000) {
    if (appmode){
    }
    else {
      btncounter ++;
    }
    btnid = 4;
    last_micros = micros();
  }
}

void setup()
{ 

  SPI.begin( /*CLK*/ 14, /*MISO*/ 12, /*MOSI*/ 13);
  SPIFFS.begin();
  mydisp.begin();

  pinMode(up, INPUT_PULLUP);
  pinMode(down, INPUT_PULLUP);
  pinMode(right, INPUT_PULLUP);
  pinMode(left, INPUT);           //External pulldown resistor (required for programming)

  attachInterrupt(digitalPinToInterrupt(up), UP, FALLING);
  attachInterrupt(digitalPinToInterrupt(down), DOWN, FALLING);
  attachInterrupt(digitalPinToInterrupt(right), RIGHT, FALLING);
  attachInterrupt(digitalPinToInterrupt(left), LEFT, FALLING);
  
  pixels.begin();
  ws2812fx.init();
  ws2812fx.setSpeed(200);

  #include "_images/hth.c"
  int h, w, buffidx;
  int row, col;
  h = 64;
  w = 100;
  buffidx = 0;
  mydisp.clearScreen(); 
//  for (row=0; row<h; row++) {
//        for (col=0; col<w; col++) { 
//          mydisp.drawPixel(col, row, pgm_read_word(image_data_hth + buffidx));
//          buffidx++;
//        } 
//   }
//   delay(2000);
//   mydisp.clearScreen();
  
  mydisp.setTextColor(GREEN);

  menu.InitMenu((const char **)mnuRoot,cntRoot,1);
  
  //Serial.begin(115200);
  //Serial.begin(38400); // Need slower comms between atmel 32u4 and esp32
  Serial.begin(57600); // Jay mentioned this is the fastest/reliable between the two chips

  loadSettings();
  all_leds_off();
  wifi_off();
  
  genWinPayloadsMenu();
  genLinPayloadsMenu();
  genStaticStringsMenu();
  
}

void menu_reset(){
  mydisp.setBrightness(oledbright);
  mydisp.setFont(&defaultFont);
  mydisp.setTextScale(1);
  //all_leds_off();
}

void all_leds_off(){
  pixels.setBrightness(ledsbright);
  for(byte i=0;i<NUMPIXELS-1;i++){
    pixels.setPixelColor(i, pixels.Color(0,0,0));
    pixels.show();
    delay(5);
  }  
}

void wifi_off(){
  WiFi.mode(WIFI_OFF);
  //WiFi.forceSleepBegin();
  delay(5);
}

void menu_force_escape(){
  btnid = 4;
  btncounter++;
}


void loop()
{ 
 
  
  int keycode=0;
  int clickedItem=0; 
  
  if (btncounter > 0)
  { 
    switch(btnid)
    {
      case 1:       
        clickedItem=menu.ProcessMenu(ACTION_SELECT);
        btncounter--;
        break;
      case 2:
        menu.ProcessMenu(ACTION_DOWN);
        btncounter--;
        break;      
      case 3:
        menu.ProcessMenu(ACTION_UP);
        btncounter--;
        break;
      case 4:
        clickedItem=menu.ProcessMenu(ACTION_BACK); 
        btncounter--;
        break;
    }
  }
  
  if (clickedItem > 0)
  {
    // Logic for root menu
    if (menu.CurrentMenu==mnuRoot)
      switch (clickedItem)
      {
        case 1:
          menu.InitMenu((const char ** )mnuLora,cntLora,1);
          break;
        case 2:
          menu.InitMenu((const char ** )mnuWiFiPassiveTools,cntWiFiPassiveTools,1);
          break;
        case 3:
          menu.InitMenu((const char ** )mnuWiFiClient,cntWiFiClient,1);
          break; 
        case 4:
          menu.InitMenu((const char ** )mnuWiFiServer,cntWiFiServer,1);
          break; 
//        case 5:
//          menu.InitMenu((const char ** )mnuBLETools,cntBLETools,1);
//          break;
        case 5:
          menu.InitMenu((const char ** )mnuBlinky,cntBlinky,1);
          break;
        case 6:
          menu.InitMenu((const char ** )mnuGraphics,cntGraphics,1);
          break;
//        case 6:
//          menu.InitMenu((const char ** )mnuMischief,cntMischief,1);
//          break; 
        case 7:
          menu.InitMenu((const char ** )mnuExtra,cntExtra,1);
          break;
        case 8:
          menu.InitMenu((const char ** )mnuSettings,cntSettings,1);
          break;
        case 9:
          menu.InitMenu((const char ** )mnuAbout,cntAbout,1);
          break;
        case 10:
          menu.InitMenu((const char ** )mnuDebug,cntDebug,1);
          break;
        case 11:
          menu.InitMenu((const char ** )mnuHIDarsenal,cntHIDarsenal,1);
          break;
      }

    // Logic for sub menus
    else if (menu.CurrentMenu==mnuHIDarsenal)
      switch (clickedItem)
      {
        case 1:
          //win kb
          menu.InitMenu((const char ** )mnuWinPayloads,cntWinPayloads,1);
          break;
        case 2:
          //lin kb
          menu.InitMenu((const char ** )mnuLinPayloads,cntLinPayloads,1);
          break;
        case 3:
          menu.MessageBox("Moving...");
          MouseJiggler();
          break;
        case 4:
          //static strings menu
          menu.InitMenu((const char ** )mnuStaticStrings,cntStaticStrings,1);
          break;
        case 5:
          GoogleAuth();
          break;
        case 6:
          break;
      }

    else if (menu.CurrentMenu==mnuWinPayloads)
      {
        runKBPayload(actualWinPayloads[clickedItem]);
      }

    else if (menu.CurrentMenu==mnuLinPayloads)
      {
        runKBPayload(actualLinPayloads[clickedItem]);
      }

    else if (menu.CurrentMenu==mnuStaticStrings)
      {
        runStaticString(actualStaticString[clickedItem]);
      }
    
    else if (menu.CurrentMenu==mnuWiFiPassiveTools)
      switch (clickedItem)
      {
        case 1:
          menu.MessageBox("Scanning...");
          AP_Channel_Usage();
          wifi_off();
          break;
        case 2:
          menu.MessageBox("Scanning...");
          AP_Scanner();
          wifi_off();
          break;
        case 3:
          Pkt_Monitor();
          //wifi_off();
          break;
        case 4:
          menu.MessageBox("Scanning...");
          Open_AP_Scanner();
          wifi_off();
          break;
        case 5:
          //DeauthMonitor();
          wifi_off();
          break;
        case 6:
          //ClientBeacons();
          //wifi_off();
          break;
      }

    else if (menu.CurrentMenu==mnuWiFiClient)
      switch (clickedItem)
      {
        case 1:
          ConnectInternet();
          break;
        case 2:
          IPConfig();
          break;
        case 3:
          NTPdisplay();
          break;
        case 4:
          menu.MessageBox("Disconnected");
          WiFi.disconnect(true);
          break;
      }

    else if (menu.CurrentMenu==mnuWiFiServer)
      switch (clickedItem)
      {
        case 1:
          APStart();
          APDisplay();
          break;
        case 2:
          APDisplay();
          break;
        case 3:
          WebServerStart();
          WebServerDisplay();
          break;
        case 4:
          WebServerDisplay();
          break;
        case 5:
          NTPstart();
          break;
        case 6:
          NTPstop();
          break;
        case 7:
          menu.MessageBox("AP off");
          APStop();
          break;
      }

//    else if (menu.CurrentMenu==mnuBLETools)
//      switch (clickedItem)
//      {
//        case 1:
//          BeaconStart();
//          break;
//        case 2:
//          BeaconStop();
//          break;
//        case 3:
//          break;
//      }

    else if (menu.CurrentMenu==mnuBlinky)
      switch (clickedItem)
      {
        case 1:
          mydisp.clearScreen();
          LED_WS2812FX_Favorites();
          break;
        case 2:
          mydisp.clearScreen();
          LED_Flashlight();
          break;
         case 3:
          mydisp.clearScreen();
          LED_WS2812FX_FullDemo();
          break;
         default:
          mydisp.clearScreen();
          byte ledmode = clickedItem - 3;
          Serial.println(ledmode);
          LED_WS2812FX(ledmode);
          break; 
      }

    else if (menu.CurrentMenu==mnuGraphics)
      switch (clickedItem)
      {
        case 1:
          SelectArtwork();
          break;
        case 2:
          GfxBenchmark();
          break;
        case 3:
          cubeDemo();
          break;
        case 4:
          clockDemo();
          break;
        case 5:
          gaugeDemo();
          break;
      }

    else if (menu.CurrentMenu==mnuMischief)
      switch (clickedItem)
      {
        case 1:
          RickRollSSID();
          break;
        default:
          menu.MessageBox("N/A");
          break;
      }

    else if (menu.CurrentMenu==mnuExtra)
      switch (clickedItem)
      {
        case 1:
          snakeGame();
          break;
        case 2:
          ButtonEcho();
          break;
        case 3:
          KeyboardDemo();
          break;
      }

    else if (menu.CurrentMenu==mnuSettings)
      switch (clickedItem)
      {
        case 1:
          menu.InitMenu((const char ** )mnuOLEDBrightness,cntOLEDBrightness,1);
          break;
        case 2:
          menu.InitMenu((const char ** )mnuLEDBrightness,cntLEDBrightness,1);
          ShowLEDBrightness();
          break;
        case 3:
          if (region_unlocked == 1) {
            menu.InitMenu((const char ** )mnuRegion,cntRegion,1);
          }
          else { menu.MessageBox("Region is Locked"); }
          break;
        case 4:
          //configuration via webserver
          mydisp.clearScreen();
          mydisp.println(F("1) Start AP"));
          mydisp.println(F("2) Start Webserver"));
          mydisp.println(F("3) Browse webserver"));
          mydisp.println(F("    and nav to config"));
          mydisp.println(F("4) Reboot after mods"));
          break;
        case 5:
          SaveSettings();
          menu.MessageBox("Settings Saved");
          delay(1000);
          menu_force_escape();
          break;
        case 6:
          break;
      }

    else if (menu.CurrentMenu==mnuOLEDBrightness)
      switch (clickedItem)
      {
        case 1:
          SaveOLEDBrightness(1);
          break;
        case 2:
          SaveOLEDBrightness(2);
          break;
        case 3:
          SaveOLEDBrightness(4);
          break;
        case 4:
          SaveOLEDBrightness(7);
          break;
        case 5:
          SaveOLEDBrightness(11);
          break;
        case 6:
          SaveOLEDBrightness(15);
          break;
      }

    else if (menu.CurrentMenu==mnuLEDBrightness)
      switch (clickedItem)
      {
        case 1:
          SaveLEDBrightness(1);
          ShowLEDBrightness();
          break;
        case 2:
          SaveLEDBrightness(10);
          ShowLEDBrightness();
          break;
        case 3:
          SaveLEDBrightness(32);
          ShowLEDBrightness();
          break;
        case 4:
          SaveLEDBrightness(64);
          ShowLEDBrightness();
          break;
        case 5:
          SaveLEDBrightness(128);
          ShowLEDBrightness();
          break;
        case 6:
          SaveLEDBrightness(184);
          ShowLEDBrightness();
          break;
        case 7:
          SaveLEDBrightness(254);
          ShowLEDBrightness();
          break;
      }
    else if (menu.CurrentMenu==mnuRegion)
      switch (clickedItem)
      {
       case 1:
          menu.MessageBox("Region Set: US");
          region_id = 1;  //US
//          if (EEPROM.read(REGION_UNLOCK_ADDR)){
//            EEPROM.write(REGION_ADDR,region_id);  
//            EEPROM.commit();
//          }
          break;
       case 2:
          menu.MessageBox("Region Set: EU");
          region_id = 2;
//          if (EEPROM.read(REGION_UNLOCK_ADDR)){
//            EEPROM.write(REGION_ADDR,region_id);  
//            EEPROM.commit();
//          }
          break;      
      }

    else if (menu.CurrentMenu==mnuAbout)
      switch (clickedItem)
      {
        case 1:
          SysInfo();
          break;
        case 2:
          HWInfo();
          break;          
        case 3:
          Credits();
          break;
        case 4:
          Shouts();
          break;
      } 

    else if (menu.CurrentMenu==mnuDebug)
      switch (clickedItem)
      {
        case 1:
          DebugInfo1();
          break;
        case 2:
          all_leds_off();
          break;
        case 3:
          wifi_off();
          break;
        case 4:
          HTTPSysUpdate();
          break;
        case 5:
          RickRollSSID();
          //rotateScreen180();
          break;
        case 6:
          //loadSettings();
          //rotateScreen180();
          break;
      } 

     else if (menu.CurrentMenu==mnuLora)
      switch (clickedItem)
      {
        case 1:
          
          lora_init();
          
          break;
      } 

    //after menu function, set brightness, set default font on display. reset leds
    menu_reset();
  }

  // menu return logic
  else if(clickedItem == -1){
    if (menu.CurrentMenu==mnuRoot)
      { /*In root menu already - Do Nothing*/ }

    //2nd level menus
    else if (menu.CurrentMenu==mnuHIDarsenal)   
      { menu.InitMenu((const char ** )mnuRoot,cntRoot,1); }
    else if (menu.CurrentMenu==mnuWiFiPassiveTools)   
      { menu.InitMenu((const char ** )mnuRoot,cntRoot,2); }
    else if (menu.CurrentMenu==mnuWiFiClient)
      { menu.InitMenu((const char ** )mnuRoot,cntRoot,3); }
    else if (menu.CurrentMenu==mnuWiFiServer)
      { menu.InitMenu((const char ** )mnuRoot,cntRoot,4); }
//    else if (menu.CurrentMenu==mnuBLETools)
//      { menu.InitMenu((const char ** )mnuRoot,cntRoot,5); }
    else if (menu.CurrentMenu==mnuBlinky)
      { menu.InitMenu((const char ** )mnuRoot,cntRoot,5); }
    else if (menu.CurrentMenu==mnuGraphics)
      { menu.InitMenu((const char ** )mnuRoot,cntRoot,6); }
//    else if (menu.CurrentMenu==mnuMischief)
//      { menu.InitMenu((const char ** )mnuRoot,cntRoot,6); }
    else if (menu.CurrentMenu==mnuExtra)
      { menu.InitMenu((const char ** )mnuRoot,cntRoot,7); }
    else if (menu.CurrentMenu==mnuSettings)
      { menu.InitMenu((const char ** )mnuRoot,cntRoot,8); }
    else if (menu.CurrentMenu==mnuAbout)
      { menu.InitMenu((const char ** )mnuRoot,cntRoot,9); }
    else if (menu.CurrentMenu==mnuDebug)
      { menu.InitMenu((const char ** )mnuRoot,cntRoot,10); }
    else if (menu.CurrentMenu==mnuLora)
      { menu.InitMenu((const char ** )mnuRoot,cntRoot,11); }

    //3rd level menus
    else if (menu.CurrentMenu==mnuOLEDBrightness)
      { menu.InitMenu((const char ** )mnuSettings,cntSettings,1); }
    else if (menu.CurrentMenu==mnuLEDBrightness)
      { menu.InitMenu((const char ** )mnuSettings,cntSettings,2); 
        all_leds_off();
      }
    else if (menu.CurrentMenu==mnuRegion)
      { menu.InitMenu((const char ** )mnuSettings,cntSettings,3); }
    else if (menu.CurrentMenu==mnuWinPayloads)
      { menu.InitMenu((const char ** )mnuHIDarsenal,cntHIDarsenal,1); }
    else if (menu.CurrentMenu==mnuLinPayloads)
      { menu.InitMenu((const char ** )mnuHIDarsenal,cntHIDarsenal,2); }
    else if (menu.CurrentMenu==mnuStaticStrings)
      { menu.InitMenu((const char ** )mnuHIDarsenal,cntHIDarsenal,4); }
    

    //after return menu, reset brightness on display
    menu_reset();

   }

  //Send reeived LoRa message back to client via websocket
  if(msgReceived == true){
     ws.textAll(storedMsg);
     msgReceived = false;
  }
}

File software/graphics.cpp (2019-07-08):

//#include <EEPROM.h>
#include <SPI.h>

#include <SSD_13XX.h>

#include "core.h"

extern SSD_13XX mydisp;
extern byte appmode;
extern byte btncounter;
extern volatile byte btnid;

extern void menu_force_escape();

////////////////////////////////////////////////////////////////////////////////////////////////////////////////////

#include "_images/hth.c"


void DisplayArtwork(byte img){
  int h, w, buffidx;
  int row, col;
  switch(img)
  {
   case 1:
      h = 64;
      w = 100;
      buffidx = 0;
      mydisp.clearScreen(); 
      for (row=0; row<h; row++) {
        for (col=0; col<w; col++) { 
          mydisp.drawPixel(col, row, pgm_read_word(image_data_hth + buffidx));
          buffidx++;
        } 
      }
      break;
  }
}

void SelectArtwork(){
  appmode=1;
  byte count=1;
  byte last=0;
  btnid = 0;
  while (btnid != 4)
  {
    if (btnid == 2){ 
      if (count == 4) {count = 1; } 
      else {count++;}
      btnid = 0;
    }
    else if (btnid == 3){ 
      if (count == 1) {count = 4; } 
      else {count--;}
      btnid = 0;
    }
    else if (btnid == 1){
//      EEPROM.write(ARTWORK_ADDR,count);
//      EEPROM.commit();
//      mydisp.clearScreen();
//      mydisp.setCursor(0, 0);
//      mydisp.setTextColor(PURPLE);
//      mydisp.setTextScale(3);
//      mydisp.println(F("Saved"));
//      delay(1000);
      btnid = 4;
      break;
    }
    else if (btnid == 4) {break;}

    if (count != last)
    {
      last=count;
      DisplayArtwork(last); 
    }
    delay(150);
  }
  appmode=0;
  btncounter++;
}

////////////////////////////////////////////////////////////////////////////////////////////////////////////////////

unsigned long testFillScreen() {
  unsigned long start = micros();
  mydisp.clearScreen();
  mydisp.fillScreen(RED);
  mydisp.fillScreen(GREEN);
  mydisp.fillScreen(BLUE);
  mydisp.clearScreen();
  return micros() - start;
}

unsigned long testText() {
  mydisp.clearScreen();
  unsigned long start = micros();
  mydisp.setCursor(0, 0);
  mydisp.setTextColor(WHITE);
  mydisp.setTextScale(1);
  mydisp.println(F("Hello World!"));
  mydisp.setTextColor(CYAN);
  mydisp.setTextScale(2);
  mydisp.println(F("1234.56"));
  mydisp.setTextColor(RED);
  mydisp.setTextScale(3);
  mydisp.println(F("0xDEAD, HEX"));
  mydisp.println();
  mydisp.setTextColor(GREEN);
  mydisp.setTextScale(4);
  mydisp.println(F("Hello"));
  return micros() - start;


}

unsigned long testText2() {
  mydisp.clearScreen();
  unsigned long start = micros();
  mydisp.setCursor(0, 0);
  mydisp.setTextColor(WHITE);
  mydisp.setTextScale(2);
  mydisp.println(F("I implore thee,"));
  mydisp.setTextScale(1);
  mydisp.println(F("my foonting turlingdromes."));
  mydisp.println(F("And hooptiously drangle me"));
  mydisp.println(F("with crinkly bindlewurdles,"));
  mydisp.println(F("Or I will rend thee"));
  mydisp.println(F("in the gobberwarts"));
  mydisp.println(F("with my blurglecruncheon,"));
  mydisp.println(F("see if I don't!"));
  return micros() - start;
}

unsigned long testLines(uint16_t color) {
  unsigned long start, t;
  int           x1, y1, x2, y2,
                w = mydisp.width(),
                h = mydisp.height();

  mydisp.clearScreen();

  x1 = y1 = 0;
  y2    = h - 1;
  start = micros();
  for (x2 = 0; x2 < w; x2 += 6) mydisp.drawLine(x1, y1, x2, y2, color);
  x2    = w - 1;
  for (y2 = 0; y2 < h; y2 += 6) mydisp.drawLine(x1, y1, x2, y2, color);
  t     = micros() - start; // fillScreen doesn't count against timing

  mydisp.clearScreen();

  x1    = w - 1;
  y1    = 0;
  y2    = h - 1;
  start = micros();
  for (x2 = 0; x2 < w; x2 += 6) mydisp.drawLine(x1, y1, x2, y2, color);
  x2    = 0;
  for (y2 = 0; y2 < h; y2 += 6) mydisp.drawLine(x1, y1, x2, y2, color);
  t    += micros() - start;

  mydisp.clearScreen();

  x1    = 0;
  y1    = h - 1;
  y2    = 0;
  start = micros();
  for (x2 = 0; x2 < w; x2 += 6) mydisp.drawLine(x1, y1, x2, y2, color);
  x2    = w - 1;
  for (y2 = 0; y2 < h; y2 += 6) mydisp.drawLine(x1, y1, x2, y2, color);
  t    += micros() - start;

  mydisp.clearScreen();

  x1    = w - 1;
  y1    = h - 1;
  y2    = 0;
  start = micros();
  for (x2 = 0; x2 < w; x2 += 6) mydisp.drawLine(x1, y1, x2, y2, color);
  x2    = 0;
  for (y2 = 0; y2 < h; y2 += 6) mydisp.drawLine(x1, y1, x2, y2, color);

  return micros() - start;
}

unsigned long testFastLines(uint16_t color1, uint16_t color2) {
  unsigned long start;
  int           x, y, w = mydisp.width(), h = mydisp.height();

  mydisp.clearScreen();
  start = micros();
  for (y = 0; y < h; y += 5) mydisp.drawFastHLine(0, y, w, color1);
  for (x = 0; x < w; x += 5) mydisp.drawFastVLine(x, 0, h, color2);

  return micros() - start;
}

unsigned long testRects(uint16_t color) {
  unsigned long start;
  int           n, i, i2,
                cx = mydisp.width()  / 2,
                cy = mydisp.height() / 2;

  mydisp.clearScreen();
  n     = min(mydisp.width(), mydisp.height());
  start = micros();
  for (i = 2; i < n; i += 6) {
    i2 = i / 2;
    mydisp.drawRect(cx - i2, cy - i2, i, i, color);
  }

  return micros() - start;
}

unsigned long testFilledRects(uint16_t color1, uint16_t color2) {
  unsigned long start, t = 0;
  int           n, i, i2,
                cx = (mydisp.width()  / 2) - 1,
                cy = (mydisp.height() / 2) - 1;

  mydisp.clearScreen();
  n = min(mydisp.width(), mydisp.height());
  for (i = n; i > 0; i -= 6) {
    i2    = i / 2;
    start = micros();
    mydisp.fillRect(cx - i2, cy - i2, i, i, color1);
    t    += micros() - start;
    // Outlines are not included in timing results
    mydisp.drawRect(cx - i2, cy - i2, i, i, color2);
  }

  return t;
}

unsigned long testFilledCircles(uint8_t radius, uint16_t color) {
  unsigned long start;
  int x, y, w = mydisp.width(), h = mydisp.height(), r2 = radius * 2;

  mydisp.clearScreen();
  start = micros();
  for (x = radius; x < w; x += r2) {
    for (y = radius; y < h; y += r2) {
      mydisp.fillCircle(x, y, radius, color);
    }
  }

  return micros() - start;
}

unsigned long testCircles(uint8_t radius, uint16_t color) {
  unsigned long start;
  int           x, y, r2 = radius * 2,
                      w = mydisp.width()  + radius,
                      h = mydisp.height() + radius;

  // Screen is not cleared for this one -- this is
  // intentional and does not affect the reported time.
  start = micros();
  for (x = 0; x < w; x += r2) {
    for (y = 0; y < h; y += r2) {
      mydisp.drawCircle(x, y, radius, color);
    }
  }

  return micros() - start;
}

unsigned long testTriangles() {
  unsigned long start;
  int           n, i, cx = mydisp.width()  / 2 - 1,
                      cy = (mydisp.height() / 2) - 1;

  mydisp.clearScreen();
  n     = min(cx, cy);
  start = micros();
  for (i = 0; i < n; i += 5) {
    mydisp.drawTriangle(
      cx    , cy - i, // peak
      cx - i, cy + i, // bottom left
      cx + i, cy + i, // bottom right
      mydisp.Color565(0, 0, i));
  }

  return micros() - start;
}
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

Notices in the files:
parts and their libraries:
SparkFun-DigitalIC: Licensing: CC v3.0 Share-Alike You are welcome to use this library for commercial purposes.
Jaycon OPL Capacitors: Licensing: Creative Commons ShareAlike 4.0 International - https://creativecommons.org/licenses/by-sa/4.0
